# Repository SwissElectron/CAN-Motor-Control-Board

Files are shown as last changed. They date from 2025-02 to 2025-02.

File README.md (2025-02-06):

# **OpenSource CAN FD Compatible Motor Board**

This Board was designed as a part of a larger project in the making for a Robotic Arm Actuator System. The board can manipulate a BLDC motor from 24V to 48V (designed around LiPo battery packs) and with a max current rating of 20 A. 

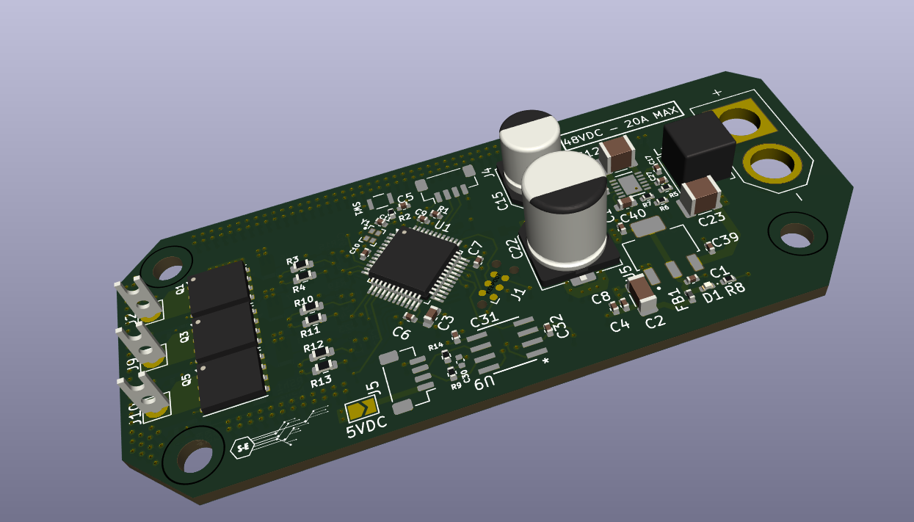
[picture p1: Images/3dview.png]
3D top view of the board


## Board Information
- STM32F103 Central Microcontroller
- Sensor-less or Wioth Sensor Control strategies 
- 24V to 48V - 20 A
- Optional 5V rail for powering sensors on the CAN Bus

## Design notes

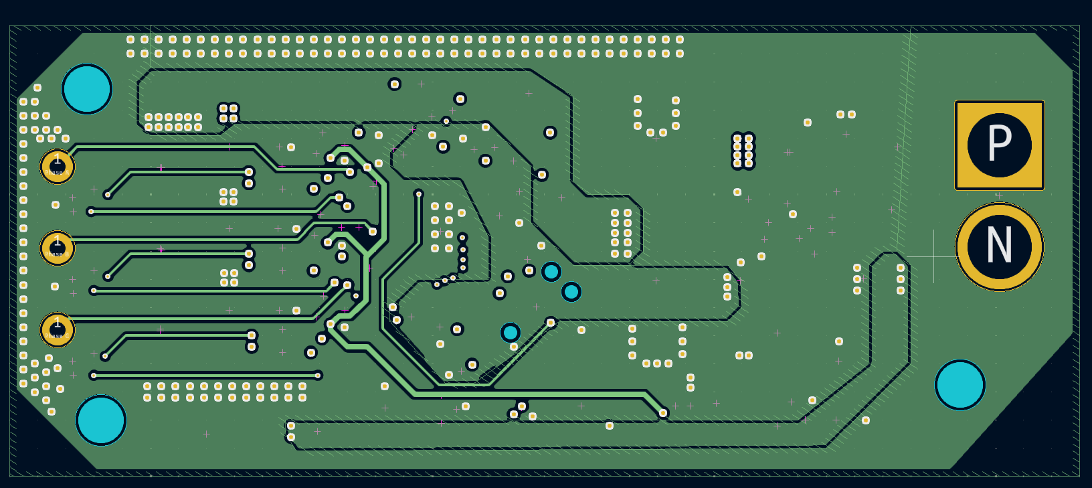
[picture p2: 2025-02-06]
Images/InCu1.png

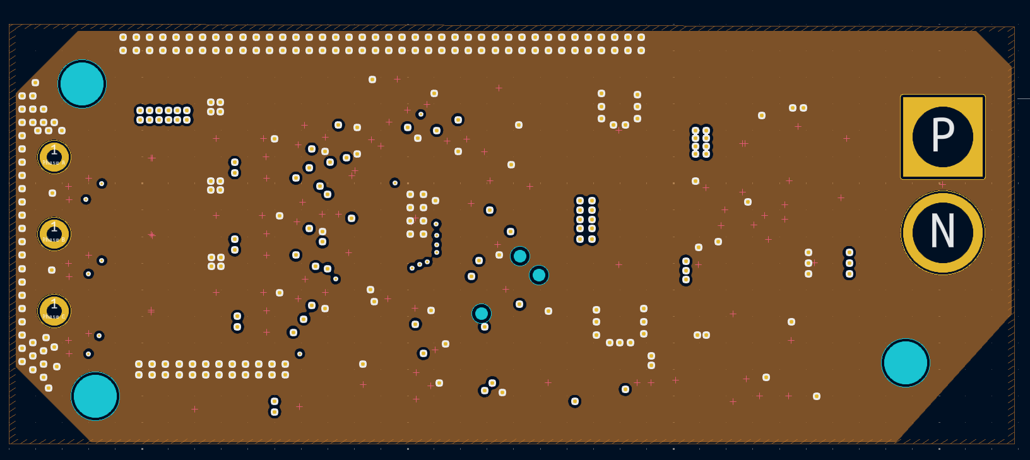
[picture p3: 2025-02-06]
Images/InCu2.png

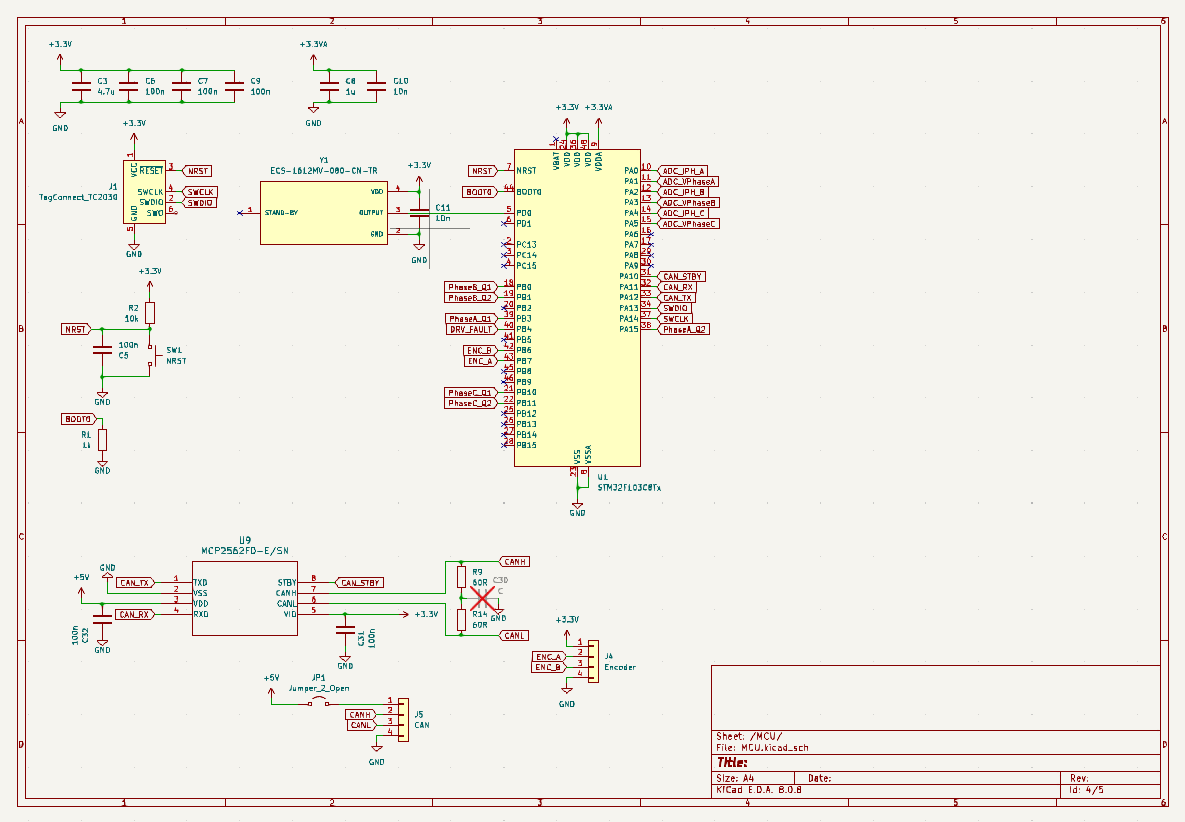
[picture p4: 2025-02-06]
Images/Microcontroller.png

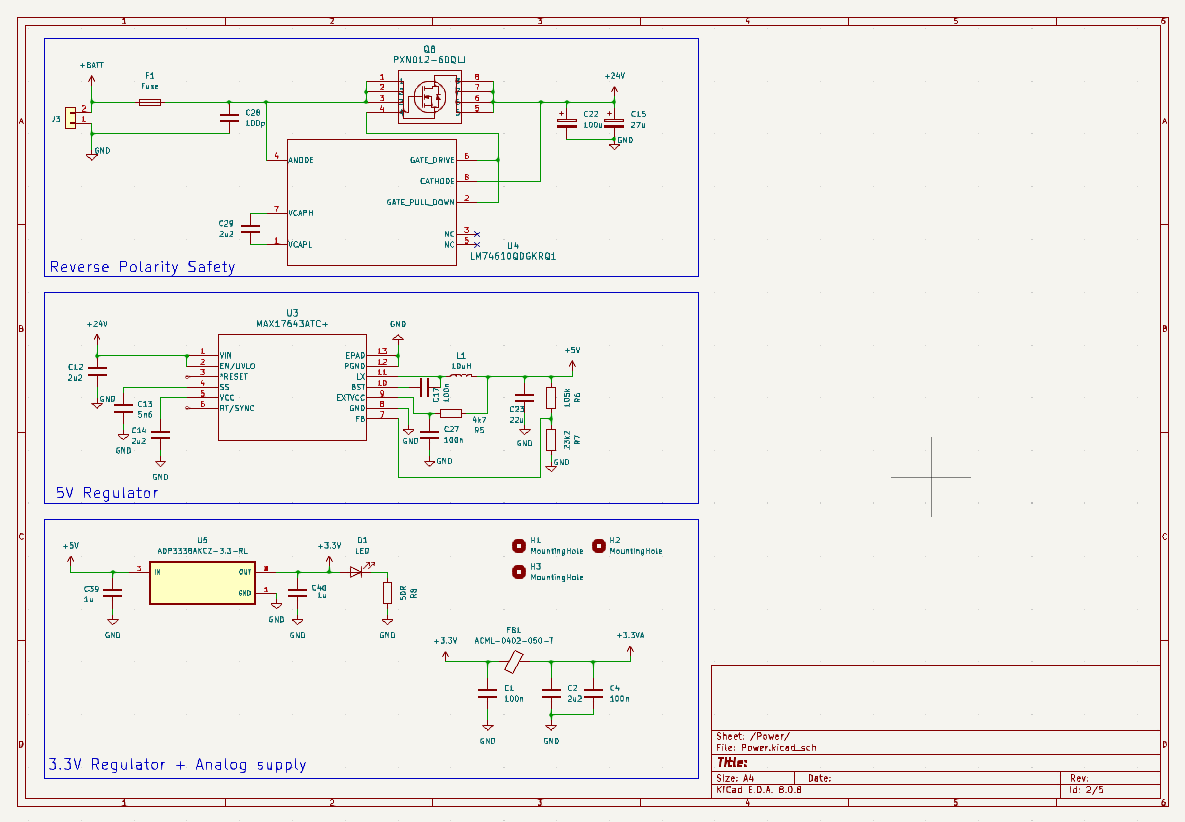
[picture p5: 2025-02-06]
Images/Power.png

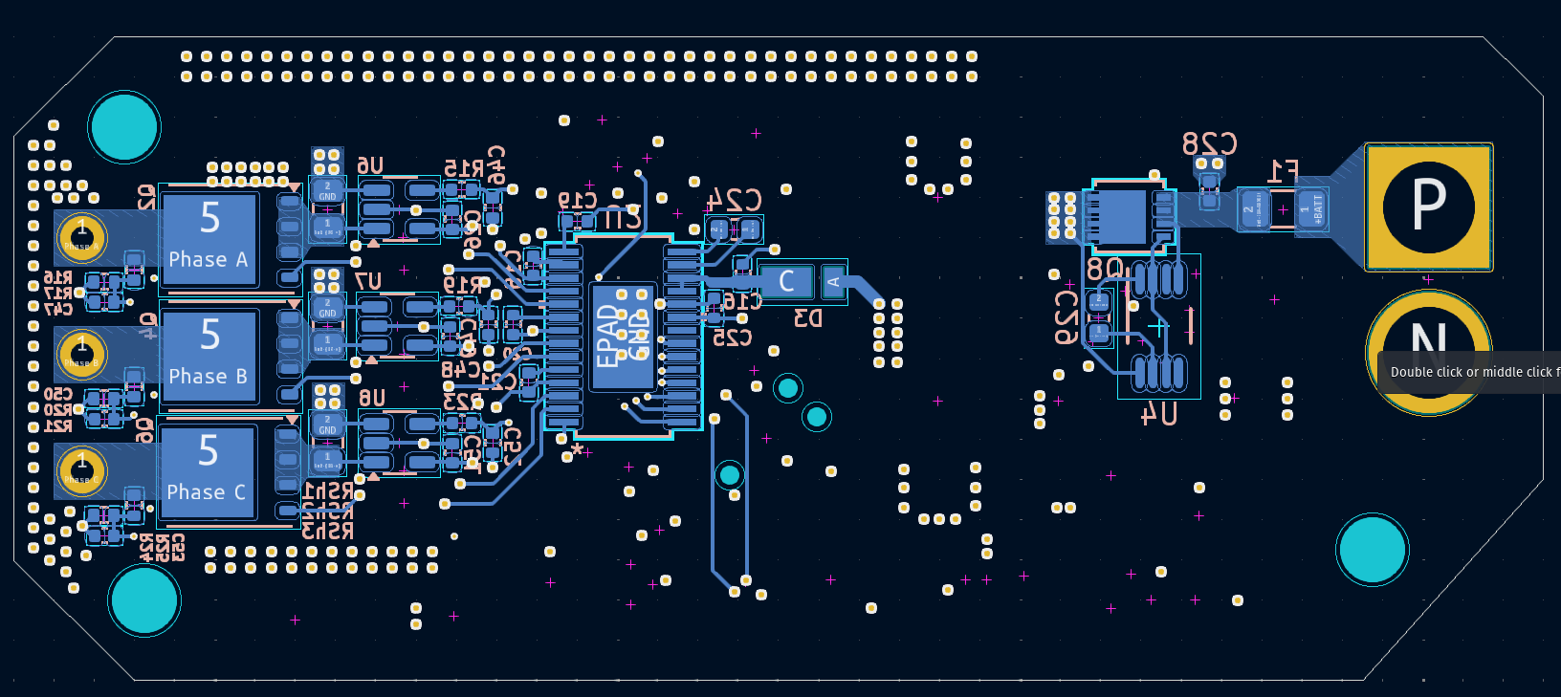
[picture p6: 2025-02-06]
Images/BackLayer.png

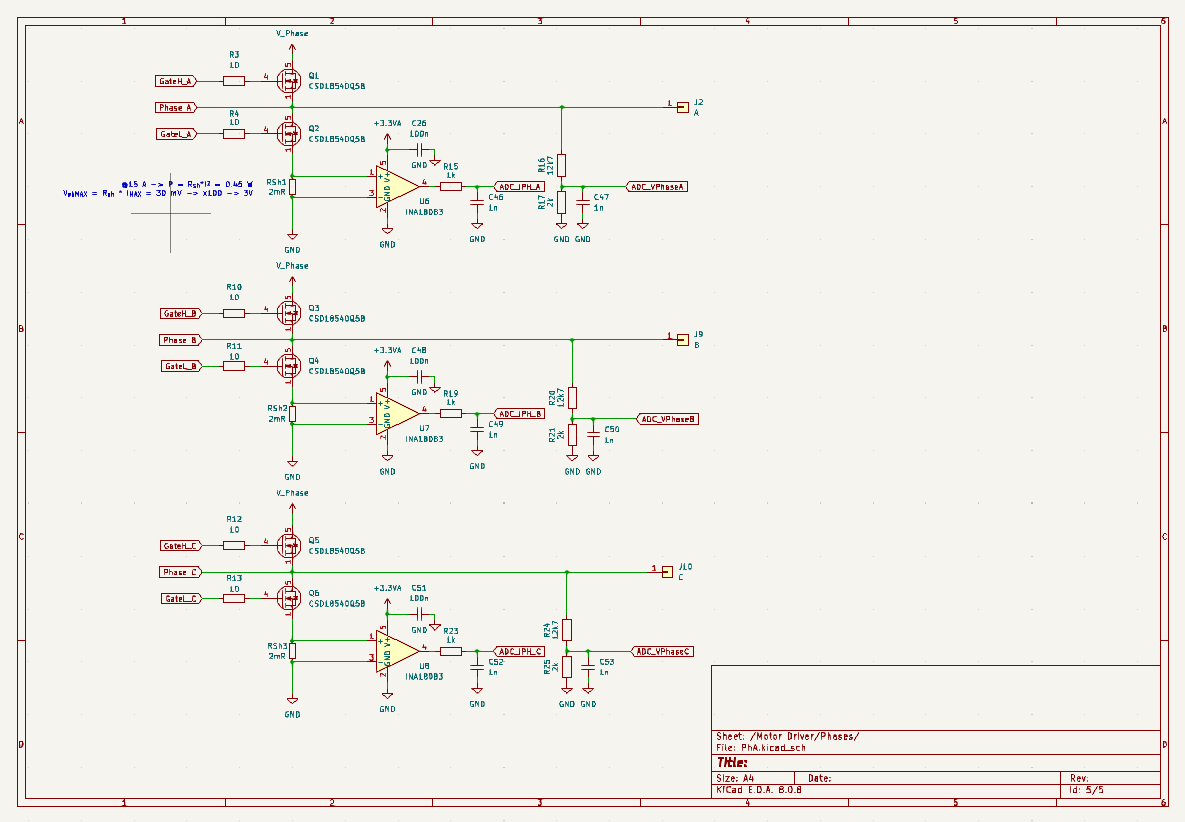
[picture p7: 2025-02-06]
Images/Phases.png

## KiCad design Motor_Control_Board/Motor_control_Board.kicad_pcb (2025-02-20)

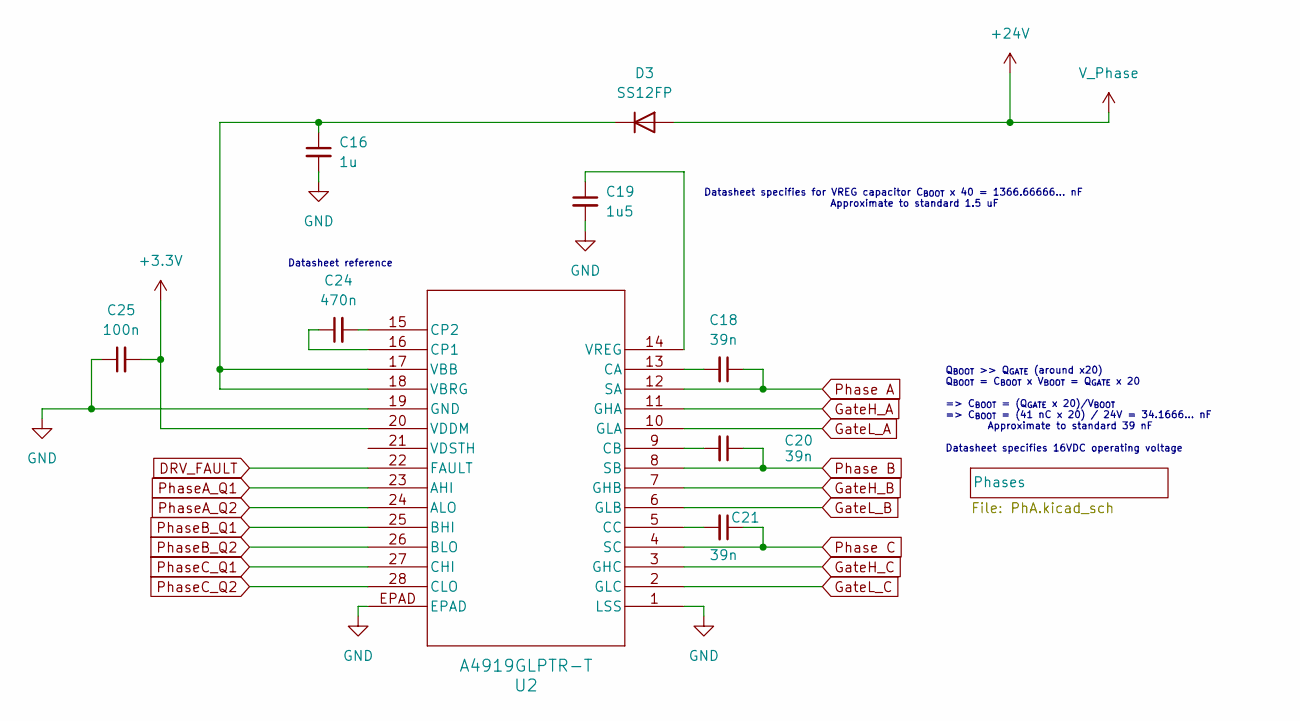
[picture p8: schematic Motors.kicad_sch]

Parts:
C16: 1u; C_0402_1005Metric; PartNum C1005X5R1C155K050BC
C18, C20, C21: 39n; C_0402_1005Metric; PartNum C0402C393J4RACTU
C19: 1u5; C_0402_1005Metric; PartNum C1005X5R1C155K050BC
C24: 470n; C_0603_1608Metric; PartNum CL10B474KO8NNWC
C25: 100n; C_0402_1005Metric; PartNum C0402C104K4PAC
D3: SS12FP; DIO_SS12LS_RVG; PartNum SS12FP
U2: A4919GLPTR-T; A4919GLPTR-T_ALM; PartNum A4919GLPTR-T

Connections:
+3.3V: C25.2, U2.20 (VDDM); also elsewhere on the board
DRV_FAULT: U2.22 (FAULT); also elsewhere on the board
GND: C16.2, C19.2, C25.1, U2.1 (LSS), U2.19 (GND), U2.EPAD; also elsewhere on the board
GateH_A: U2.11 (GHA); also elsewhere on the board
GateH_B: U2.7 (GHB); also elsewhere on the board
GateH_C: U2.3 (GHC); also elsewhere on the board
GateL_A: U2.10 (GLA); also elsewhere on the board
GateL_B: U2.6 (GLB); also elsewhere on the board
GateL_C: U2.2 (GLC); also elsewhere on the board
unnamed: C16.1, D3.1 (K), U2.17 (VBB), U2.18 (VBRG)
unnamed: C18.2, U2.13 (CA)
unnamed: C20.2, U2.9 (CB)
unnamed: C21.2, U2.5 (CC)
unnamed: C24.1, U2.16 (CP1)
unnamed: C24.2, U2.15 (CP2)
unnamed: C19.1, U2.14 (VREG)
Phase A: C18.1, U2.12 (SA); also elsewhere on the board
Phase B: C20.1, U2.8 (SB); also elsewhere on the board
Phase C: C21.1, U2.4 (SC); also elsewhere on the board
PhaseA_Q1: U2.23 (AHI); also elsewhere on the board
PhaseA_Q2: U2.24 (ALO); also elsewhere on the board
PhaseB_Q1: U2.25 (BHI); also elsewhere on the board
PhaseB_Q2: U2.26 (BLO); also elsewhere on the board
PhaseC_Q1: U2.27 (CHI); also elsewhere on the board
PhaseC_Q2: U2.28 (CLO); also elsewhere on the board

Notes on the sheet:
Q_{BOOT} >> Q_{GATE} (around x20) Q_{BOOT} = C_{BOOT} x V_{BOOT} = Q_{GATE} x 20 => C_{BOOT} = (Q_{GATE} x 20)/V_{BOOT} => C_{BOOT} = (41 nC x 20) / 24V = 34.1666... nF Approximate to standard 39 nF Datasheet specifies 16VDC operating voltage
Datasheet reference
Datasheet specifies for VREG capacitor C_{BOOT} x 40 = 1366.66666... nF Approximate to standard 1.5 uF

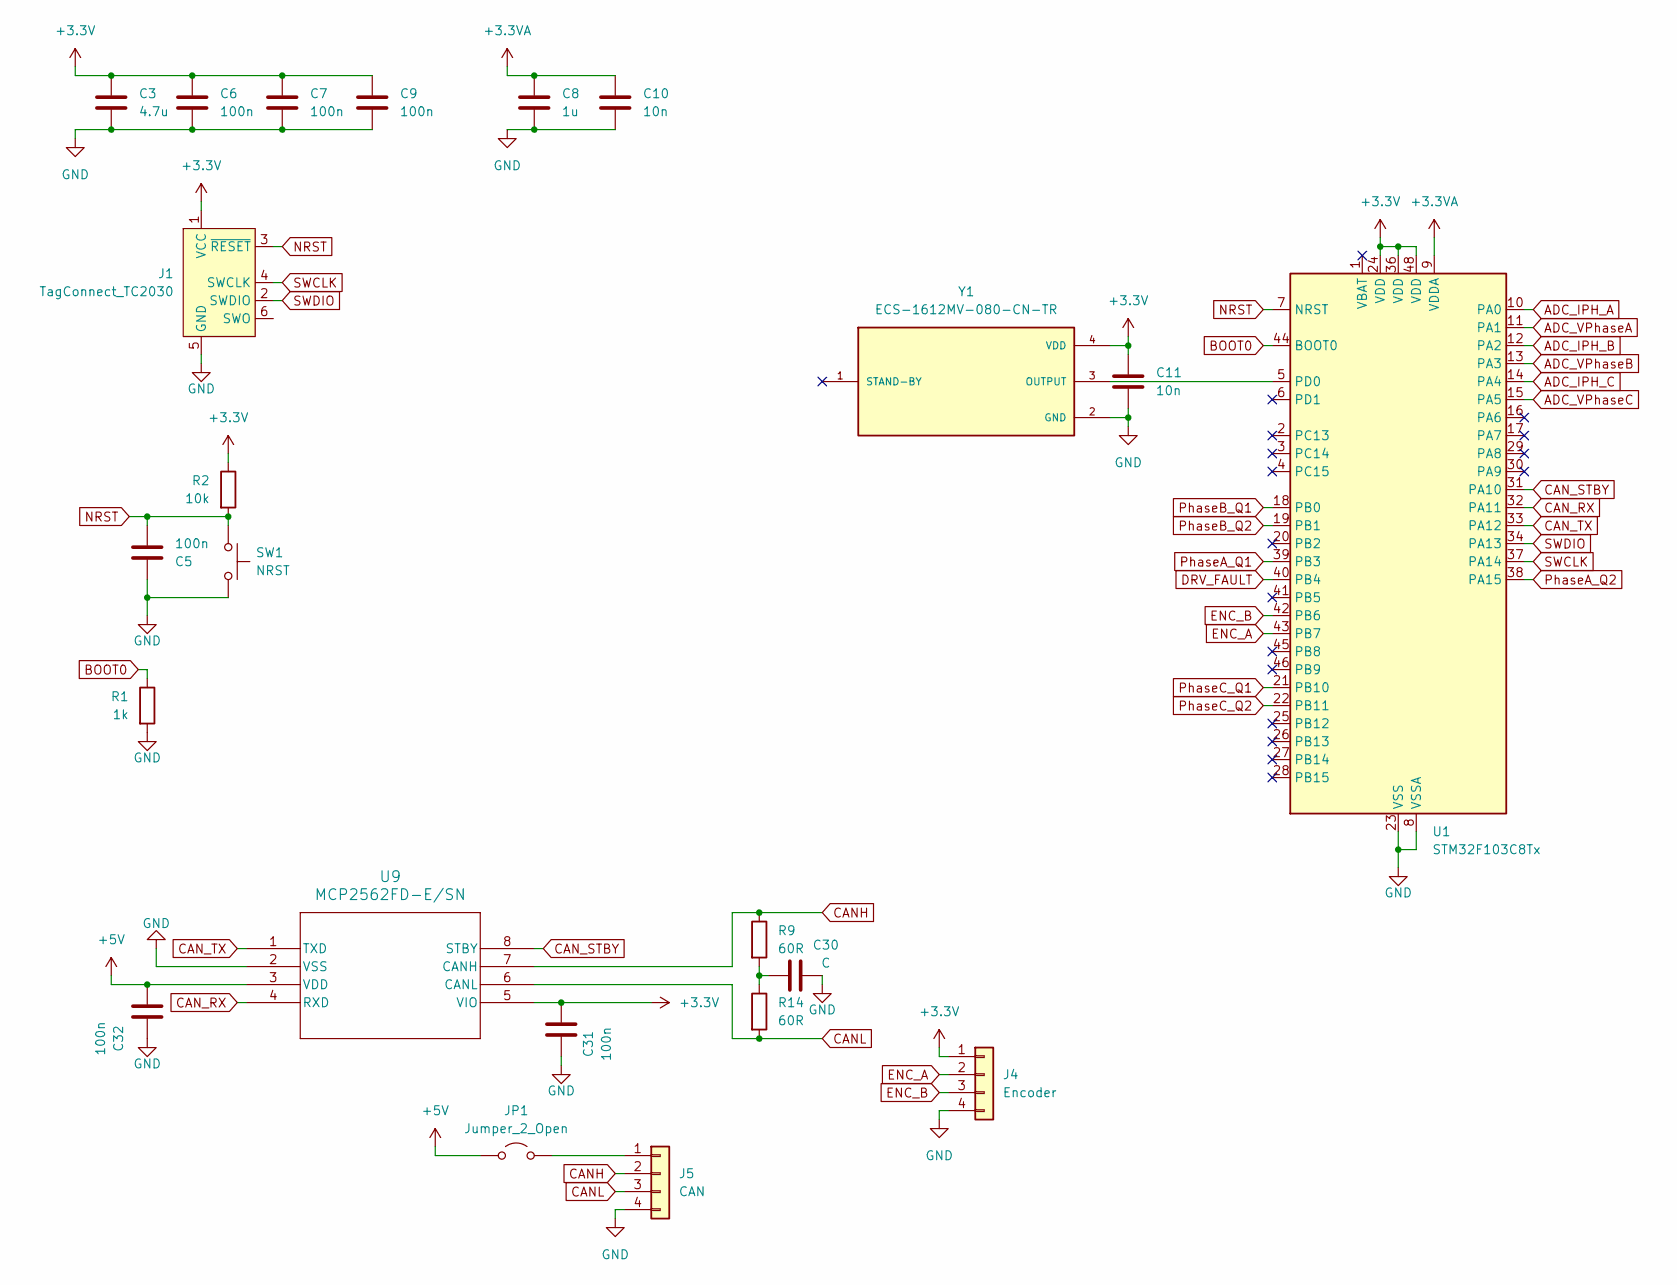
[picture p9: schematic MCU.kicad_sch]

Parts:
C3: 4.7u; C_0603_1608Metric; PartNum C0603C475M9PAC
C5, C6, C7, C9: 100n; C_0402_1005Metric; PartNum C0402C104K4PAC
C8: 1u; C_0402_1005Metric; PartNum GMD155R60J105KE11D
C10, C11: 10n; C_0402_1005Metric; PartNum GMD155R60J105KE11D
C30: C; C_0402_1005Metric
C31: 100n; C_0402_1005Metric; PartNum C0402C104K8RAC
C32: 100n; C_0402_1005Metric; PartNum GRM155R60J104MA01J
J1: TagConnect_TC2030; Tag-Connect_TC2030-IDC-NL_2x03_P1.27mm_Vertical
J4: Encoder; Molex_Pico-Clasp_501331-0407_1x04-1MP_P1.00mm_Vertical
J5: CAN; Molex_Pico-Clasp_501331-0407_1x04-1MP_P1.00mm_Vertical
JP1: Jumper_2_Open; SolderJumper-2_P1.3mm_Open_TrianglePad1.0x1.5mm
R1: 1k; C_0402_1005Metric; PartNum 0402WGF1001TCE
R2: 10k; R_0402_1005Metric; PartNum 0402WGF1002TCE
R9, R14: 60R; R_0402_1005Metric; PartNum 560112110170
SW1: NRST; NANOT100AS; PartNum NANOT100AS
U1: STM32F103C8Tx; LQFP-48_7x7mm_P0.5mm; PartNum STM32F103C8T7
U9: MCP2562FD-E/SN; MCP2562FD-ESN; PartNum MCP2562FD-E/SN
Y1: ECS-1612MV-080-CN-TR; OSC_ECS-1612MV-080-CN-TR-4; PartNum ECS-1612MV-080-CN-TR

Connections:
+3.3V: C3.1, C6.1, C7.1, C9.1, C11.1, C31.2, J1.1 (VCC), J4.1, R2.1, U1.24 (VDD), U1.36 (VDD), U1.48 (VDD), U9.5 (VIO), Y1.4 (VDD); also elsewhere on the board
+3.3VA: C8.1, C10.1, U1.9 (VDDA); also elsewhere on the board
+5V: C32.1, JP1.1 (A), U9.3 (VDD); also elsewhere on the board
ADC_IPH_A: U1.10 (PA0); also elsewhere on the board
ADC_IPH_B: U1.12 (PA2); also elsewhere on the board
ADC_IPH_C: U1.14 (PA4); also elsewhere on the board
ADC_VPhaseA: U1.11 (PA1); also elsewhere on the board
ADC_VPhaseB: U1.13 (PA3); also elsewhere on the board
ADC_VPhaseC: U1.15 (PA5); also elsewhere on the board
BOOT0: R1.1, U1.44 (BOOT0)
CANH: J5.2, R9.1, U9.7 (CANH)
CANL: J5.3, R14.2, U9.6 (CANL)
CAN_RX: U1.32 (PA11), U9.4 (RXD)
CAN_STBY: U1.31 (PA10), U9.8 (STBY)
CAN_TX: U1.33 (PA12), U9.1 (TXD)
DRV_FAULT: U1.40 (PB4); also elsewhere on the board
ENC_A: J4.2, U1.43 (PB7)
ENC_B: J4.3, U1.42 (PB6)
GND: C3.2, C5.1, C6.2, C7.2, C8.2, C9.2, C10.2, C11.2, C30.2, C31.1, C32.2, J1.5 (GND), J4.4, J5.4, R1.2, SW1.2, U1.8 (VSSA), U1.23 (VSS), U1.35 (VSS), U1.47 (VSS), U9.2 (VSS), Y1.2 (GND); also elsewhere on the board
NRST: C5.2, J1.3 (~RESET), R2.2, SW1.1, U1.7 (NRST)
unnamed: C30.1, R9.2, R14.1
unnamed 31: J5.1, JP1.2 (B); also elsewhere on the board
unnamed: U1.5 (PD0), Y1.3 (OUTPUT)
PhaseA_Q1: U1.39 (PB3); also elsewhere on the board
PhaseA_Q2: U1.38 (PA15); also elsewhere on the board
PhaseB_Q1: U1.18 (PB0); also elsewhere on the board
PhaseB_Q2: U1.19 (PB1); also elsewhere on the board
PhaseC_Q1: U1.21 (PB10); also elsewhere on the board
PhaseC_Q2: U1.22 (PB11); also elsewhere on the board
SWCLK: J1.4 (SWCLK), U1.37 (PA14)
SWDIO: J1.2 (SWDIO), U1.34 (PA13)

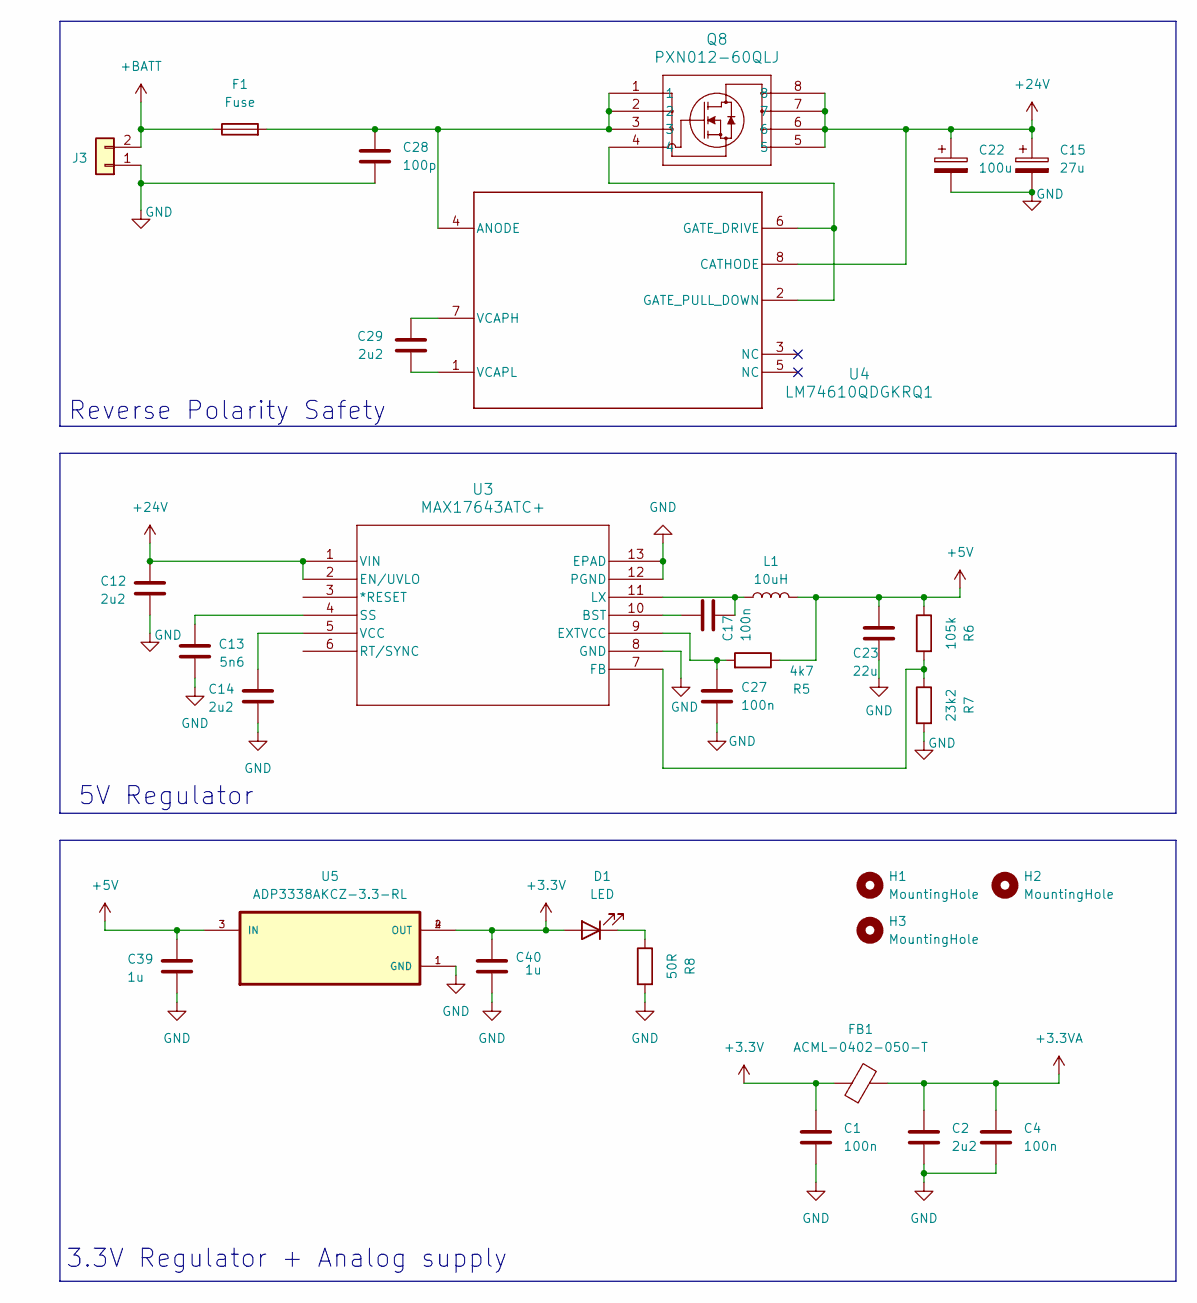
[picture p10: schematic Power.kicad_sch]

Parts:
C1, C4: 100n; C_0402_1005Metric; PartNum GCM1555C1H240FA16J
C2: 2u2; C_1206_3216Metric; PartNum C1206C225M5REC7210
C12: 2u2; C_1210_3225Metric; PartNum GRM32ER72A225KA35L
C13: 5n6; C_0402_1005Metric; PartNum GMD155R60J105KE11D
C14, C29: 2u2; C_0603_1608Metric; PartNum GRM188R71A225KE15
C15: 27u; CP_Elec_6.3x7.7; PartNum UUD1H270MCL1GS
C17, C27: 100n; C_0402_1005Metric; PartNum GMD155R60J105KE11D
C22: 100u; CP_Elec_8x10; PartNum UWT1H101MNL1GS
C23: 22u; C_1210_3225Metric; PartNum GRM32ER71C226KEA8
C28: 100p; C_0402_1005Metric; PartNum GRM0225C1H101JA02L
C39, C40: 1u; C_0402_1005Metric; PartNum GMD155R60J105KE11D
D1: LED; LED_0402_1005Metric; PartNum LTST-C281KGKT
F1: Fuse; Fuse_1206_3216Metric; PartNum SF-1206HH3000R-2
FB1: ACML-0402-050-T; L_0402_1005Metric; PartNum ACML-0402-050-T
H1, H2, H3: MountingHole; MountingHole_3.2mm_M3_DIN965
J3: Conn_01x02; AMASS_XT60-M
L1: 10uH; L_Coilcraft_XAL5050-XXX; PartNum XAL5050-103MEC
Q8: PXN012-60QLJ; PartNum PXN012-60QLJ
R5: 4k7; R_0402_1005Metric; PartNum HP02WAJ0472TCE
R6: 105k; R_0402_1005Metric; PartNum RC0402FR-07105KL
R7: 23k2; R_0402_1005Metric; PartNum CRCW040223K2FKED
R8: 50R; R_0402_1005Metric; PartNum RC0402JR-0750RL
U3: MAX17643ATC+; MAX17643; PartNum MAX17643ATC+
U4: LM74610QDGKRQ1; PartNum LM74610QDGKRQ1
U5: ADP3338AKCZ-3.3-RL; ADP3338AKCz-3.3; PartNum ADP3338AKCZ-3.3-RL

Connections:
+3.3V: C1.1, C40.2, D1.2 (A), FB1.1, U5.2 (OUT), U5.4 (OUT); also elsewhere on the board
+3.3VA: C2.1, C4.1, FB1.2; also elsewhere on the board
+5V: C23.1, C39.1, L1.2, R5.1, R6.1, U5.3 (IN); also elsewhere on the board
+24V: C12.1, C15.1, C22.1, Q8.5, Q8.6, Q8.7, Q8.8, U3.1 (VIN), U3.2 (EN/UVLO), U4.8 (CATHODE); also elsewhere on the board
+BATT: F1.1, J3.2
GND: C1.2, C2.2, C4.2, C12.2, C13.2, C14.2, C15.2, C22.2, C23.2, C27.2, C28.2, C39.2, C40.1, J3.1, R7.2, R8.2, U3.8 (GND), U3.12 (PGND), U3.13 (EPAD), U5.1 (GND); also elsewhere on the board
unnamed: D1.1 (K), R8.1
unnamed: C17.1, U3.10 (BST)
unnamed: C27.1, R5.2, U3.9 (EXTVCC)
unnamed: R6.2, R7.1, U3.7 (FB)
unnamed: C17.2, L1.1, U3.11 (LX)
unnamed: C13.1, U3.4 (SS)
unnamed: C14.1, U3.5 (VCC)
unnamed: C28.1, F1.2, Q8.1, Q8.2, Q8.3, U4.4 (ANODE)
unnamed: Q8.4, U4.2 (GATE_PULL_DOWN), U4.6 (GATE_DRIVE)
unnamed: C29.1, U4.7 (VCAPH)
unnamed: C29.2, U4.1 (VCAPL)

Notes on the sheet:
Reverse Polarity Safety
3.3V Regulator + Analog supply
5V Regulator

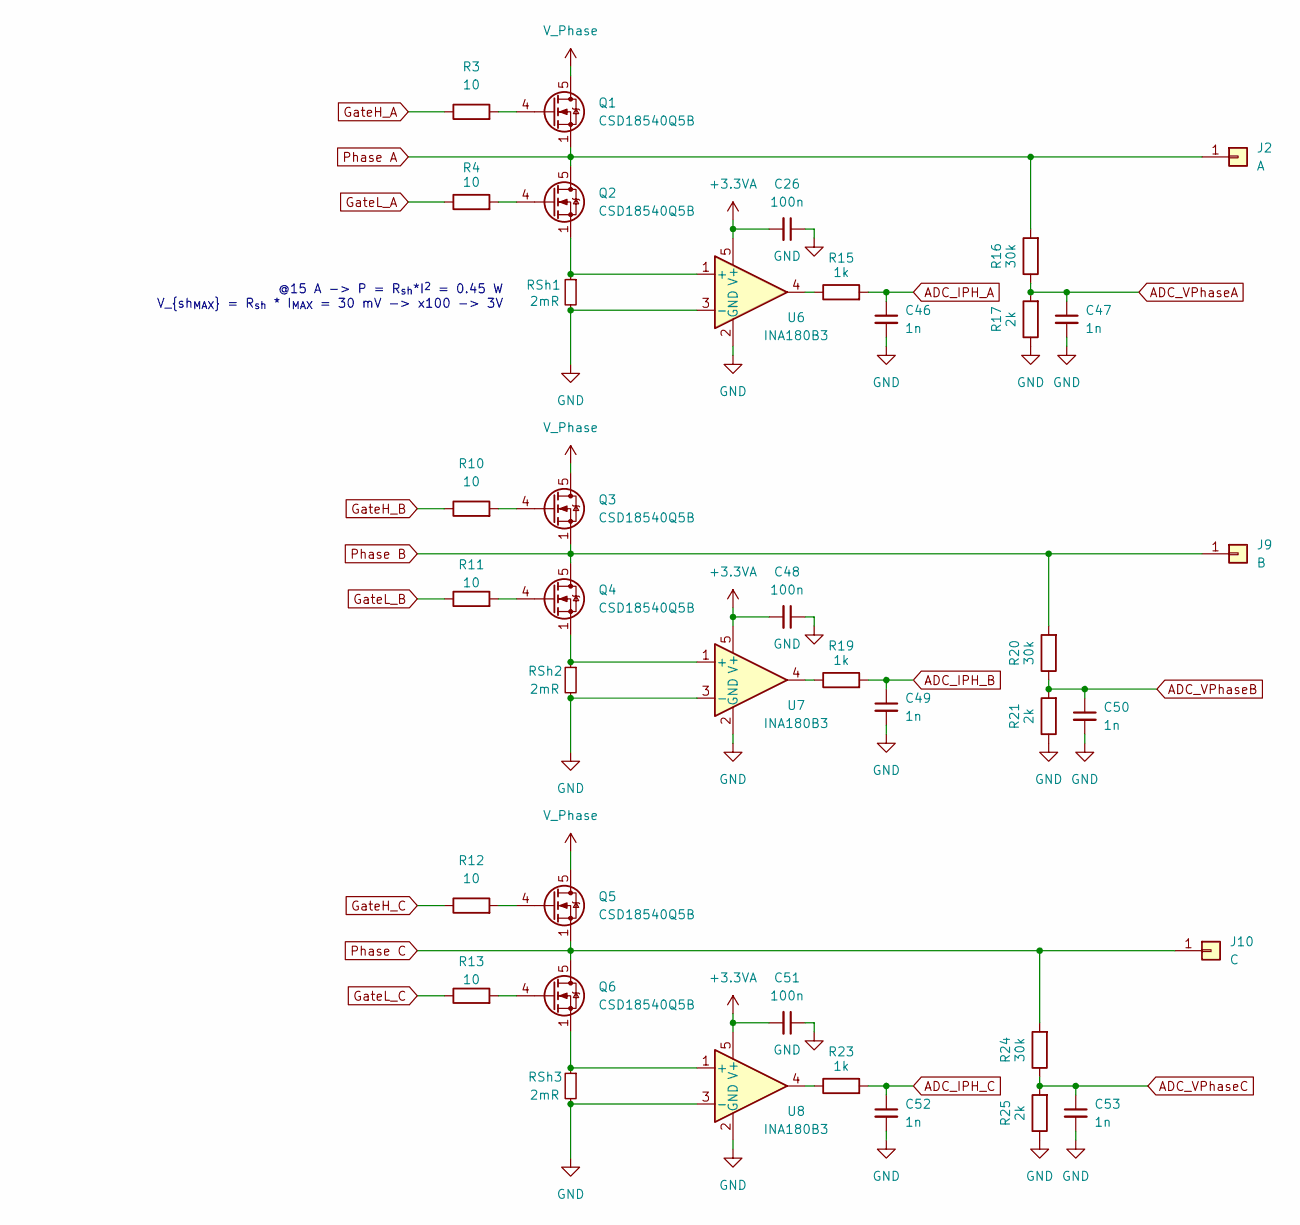
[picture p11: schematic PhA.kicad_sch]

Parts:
C26, C48, C51: 100n; C_0402_1005Metric; PartNum C0402C104K4PAC
C46, C47, C49, C50, C52, C53: 1n; C_0402_1005Metric; PartNum 885012005018
J2: A; Pin_D1.1mm_L8.5mm_W2.5mm_FlatFork
J9: B; Pin_D1.1mm_L8.5mm_W2.5mm_FlatFork
J10: C; Pin_D1.1mm_L8.5mm_W2.5mm_FlatFork
Q1, Q2, Q3, Q4, Q5, Q6: CSD18540Q5B; TDSON-8-1; PartNum CSD18540Q5B
R3, R4, R10, R11, R12, R13: 10; R_0603_1608Metric; PartNum PCAN0603E10R0BST3
R15, R19, R23: 1k; C_0402_1005Metric; PartNum 0402WGF1001TCE
R16, R20, R24: 30k; R_0402_1005Metric; PartNum CQ02WGF1272TCE
R17, R21, R25: 2k; R_0402_1005Metric; PartNum HP02WAJ0202TCE
RSh1, RSh2, RSh3: 2mR; R_0805_2012Metric; PartNum L4CL2512LR002FYR
U6, U7, U8: INA180B3; SOT-23-5; PartNum INA180B3QDBVRQ1

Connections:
+3.3VA: C26.2, C48.2, C51.2, U6.5 (V+), U7.5 (V+), U8.5 (V+); also elsewhere on the board
+24V: Q1.5 (D), Q3.5 (D), Q5.5 (D); also elsewhere on the board
ADC_IPH_A: C46.1, R15.2; also elsewhere on the board
ADC_IPH_B: C49.1, R19.2; also elsewhere on the board
ADC_IPH_C: C52.1, R23.2; also elsewhere on the board
ADC_VPhaseA: C47.1, R16.1, R17.2; also elsewhere on the board
ADC_VPhaseB: C50.1, R20.1, R21.2; also elsewhere on the board
ADC_VPhaseC: C53.1, R24.1, R25.2; also elsewhere on the board
GND: C26.1, C46.2, C47.2, C48.1, C49.2, C50.2, C51.1, C52.2, C53.2, R17.1, R21.1, R25.1, RSh1.2, RSh2.2, RSh3.2, U6.2 (GND), U6.3 (-), U7.2 (GND), U7.3 (-), U8.2 (GND), U8.3 (-); also elsewhere on the board
GateH_A: R3.1; also elsewhere on the board
GateH_B: R10.1; also elsewhere on the board
GateH_C: R12.1; also elsewhere on the board
GateL_A: R4.1; also elsewhere on the board
GateL_B: R11.1; also elsewhere on the board
GateL_C: R13.1; also elsewhere on the board
unnamed: Q1.4 (G), R3.2
unnamed: Q2.4 (G), R4.2
unnamed: Q3.4 (G), R10.2
unnamed: Q4.4 (G), R11.2
unnamed: Q5.4 (G), R12.2
unnamed: Q6.4 (G), R13.2
unnamed: R15.1, U6.4
unnamed: R19.1, U7.4
unnamed: R23.1, U8.4
unnamed: Q2.1 (S), Q2.2 (S), Q2.3 (S), RSh1.1, U6.1 (+)
unnamed: Q4.1 (S), Q4.2 (S), Q4.3 (S), RSh2.1, U7.1 (+)
unnamed: Q6.1 (S), Q6.2 (S), Q6.3 (S), RSh3.1, U8.1 (+)
Phase A: J2.1, Q1.1 (S), Q1.2 (S), Q1.3 (S), Q2.5 (D), R16.2; also elsewhere on the board
Phase B: J9.1, Q3.1 (S), Q3.2 (S), Q3.3 (S), Q4.5 (D), R20.2; also elsewhere on the board
Phase C: J10.1, Q5.1 (S), Q5.2 (S), Q5.3 (S), Q6.5 (D), R24.2; also elsewhere on the board

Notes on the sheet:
@15 A -> P = R_{sh}*I^{2} = 0.45 W V_{sh_{MAX}} = R_{sh} * I_{MAX} = 30 mV -> x100 -> 3V

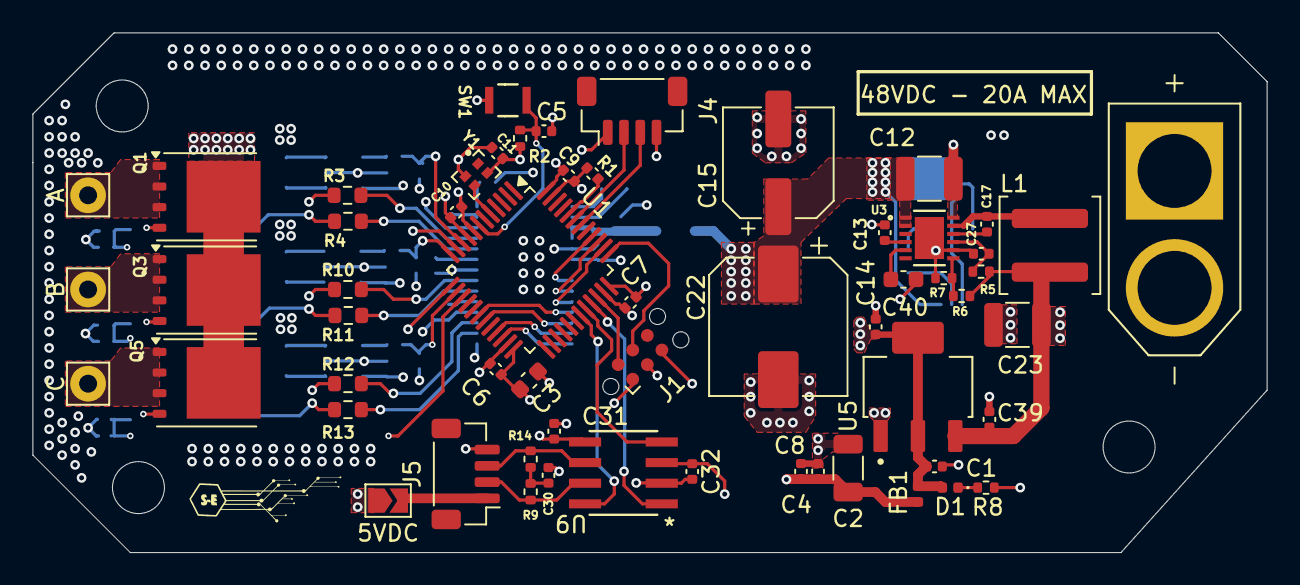
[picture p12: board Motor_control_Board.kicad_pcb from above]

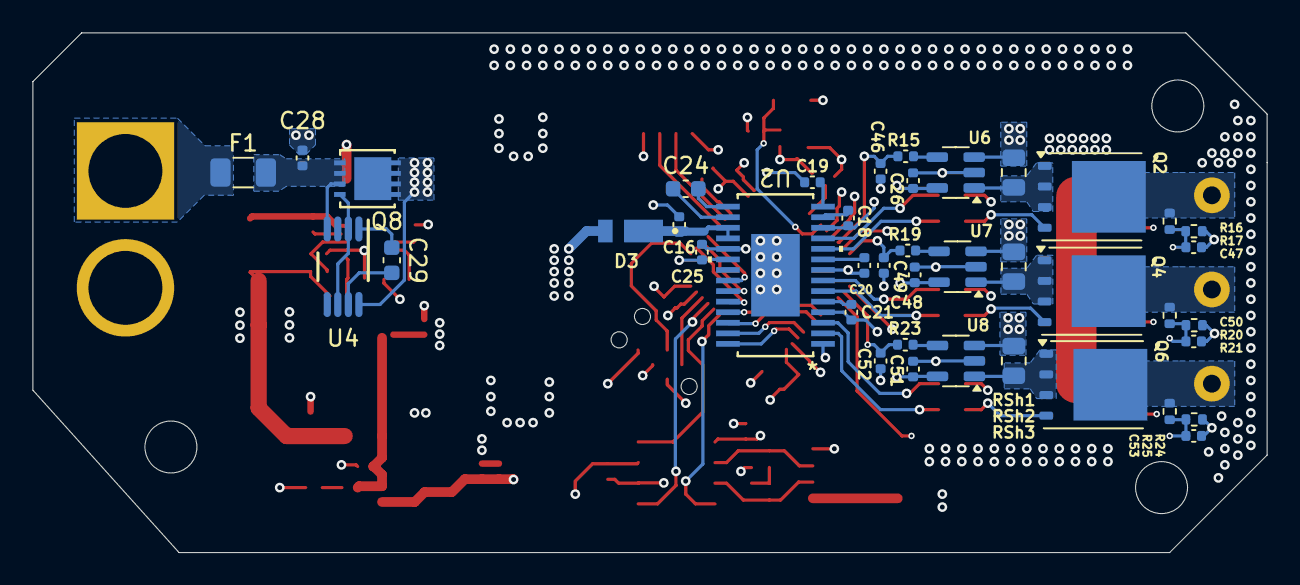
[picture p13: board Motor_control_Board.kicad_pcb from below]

Board: 4 copper layers, 76.0 x 32.0 mm, 102 parts (41 on the bottom side), 71 nets.

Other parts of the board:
5VDC: Jumper_2_Open; SolderJumper-2_P1.3mm_Open_TrianglePad1.0x1.5mm
A: A; Pin_D1.1mm_L8.5mm_W2.5mm_FlatFork
B: B; Pin_D1.1mm_L8.5mm_W2.5mm_FlatFork
C: C; Pin_D1.1mm_L8.5mm_W2.5mm_FlatFork

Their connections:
+5V: 5VDC.1 (A); also elsewhere on the board
unnamed 31: 5VDC.2 (B); also elsewhere on the board
Phase A: A.1; also elsewhere on the board
Phase B: B.1; also elsewhere on the board
Phase C: C.1; also elsewhere on the board

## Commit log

2025-02-05 Initial Commit: V0.8
    [MCU.kicad_sch, Motor_control_Board.kicad_pcb, Motor_control_Board.kicad_sch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]
2025-02-06 Minor updates: V0.9
    [MCU.kicad_sch, Motor_control_Board.kicad_pcb, Motor_control_Board.kicad_sch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]
2025-02-20 V0.10 - chnaged Volatge Sensing resistors to enable 48V sensing
    [MCU.kicad_sch, Motor_control_Board.kicad_pcb, Motors.kicad_sch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]
